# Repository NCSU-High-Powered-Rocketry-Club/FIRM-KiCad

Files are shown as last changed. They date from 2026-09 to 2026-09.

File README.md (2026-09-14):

# FIRM — Filtered Inertial Rotational Module

This repository contains the KiCad project files for the Filtered Inertial Rotational Module (FIRM). FIRM is a high-performance inertial sensing and rotation sensing module developed for flight instrumentation and payload monitoring. The repository includes schematic symbols, PCB footprints, 3D models, and all board files necessary to review, edit and manufacture the module.

---

## Quick Start — open the project

1. Install KiCad (see [Install & Setup](#install--setup-kicad) below).
2. Clone the repository:
```bash
git clone https://github.com/NCSU-High-Powered-Rocketry-Club/FIRM-KiCad.git
```

---

## Install & Setup

First, install KiCad from [kicad.org](https://kicad.org/download/). We recommend using the latest stable release of KiCad for new designs.

### After installation
- Open the `FIRM.kicad_pro` project. KiCad will use the `sym-lib-table` and `fp-lib-table` files included here if you open the board/schematic from this checkout.
- If KiCad shows missing library warnings, update the Project Library Tables or use the library manager to add the project's `sym-lib-table` and `fp-lib-table`.

---

## Repository structure

Root-level description (key files/folders):

- `FIRM.kicad_sch` — schematic
- `FIRM.kicad_pcb` — PCB layout
- `FIRM.kicad_pro` — KiCad project file that links schematics, board and library tables
- `sym-lib-table` — project symbol library table that makes project-local symbols available to Eeschema
- `fp-lib-table` — project footprint library table that makes project-local footprints available
- `3dmodels/` — 3D STEP/WRL models used with footprints
- `symbols/` — human-editable symbol libraries (e.g., `connectors.kicad_sym`, `sensors.kicad_sym`)
- `footprints/` — footprint libraries as `.pretty` directories
- `FIRM_Interestlaunch/` — FIRM variant which was milled in the Makerspace.

---

## Library handling

We keep the component libraries inside the HPRC-KiCad-Library so that components can be reused across different HPRC projects.

Make sure to follow the "Setup" instructions [here](
https://github.com/NCSU-High-Powered-Rocketry-Club/HPRC-KiCad-Library)

---

## Good Practices & Design Rules

- Keep schematic symbols generic and footprints specific: do not hardcode assembly-side changes into symbols.
- Look at the existing schematic to see how we do things and try to be consistent.
- Save new libraries to the project-local tables (not global) to keep designs reproducible.
- Keep PCB footprints accurate — use accurate courtyard, 3D models, and update packaging information.
- Validate with DRC (PCB Editor > Inspect > Design Rules Checker) and ERC (Eeschema > Tools > ERC) before committing changes.
- When collaborating, include notes about part sources (Mouser/Digikey vendor links), footprints used, and any custom pad or thickness changes.

---

## Release & Manufacturing Checklist

Before requesting fab or assembling a board, run this checklist:
1. Run ERC (Eeschema > Tools > ERC) and fix all warnings.
2. Run DRC in PCB Editor and resolve all errors.
3. Create a BOM and confirm manufacturer part numbers and footprints match.
4. Generate Gerbers and drill files (Plot + Generate Drill Files) and inspect them in GerbView.
5. Check 3D model alignment in PCB Editor (View > 3D Viewer) to ensure components fit.
6. Tag or branch the repo in Git to preserve the release snapshot.

---

## Git Collaboration and Merge Process

KiCad collaboration using git is difficult due to the KiCad file format. For example, moving a few symbols in a schematic will cause many lines to be edited, which greatly increases the chances of merge conflicts.
1. Create an issue for your feature if there isn't one already.
2. Create a branch including your name and the issue number ex: name-fix-XX or name-add-XX
    - It is best practice to suffix your branch name with a very short description/wordrelated to your change
3. Implement your change on your branch
4. Create a pull request (PR) for your change. Make sure to include images of the schematic or pcb design as well as reasons behind design decision. Request reviews from the issue creator or relevant contributors. You should need one approval to merge.
5. Merge your change into main. You will probably have to and should be able to force merge into main. 
    - However, if someone made change in between the time your branched from main and need to merge, you will have to do an unconvential merge process. 
    - You need a clean branch off the new main for this; this clean branch can either be a new branch you create, or your feature branch with all your changes reverted with main force merged into it. Then, access your changes and copy (ctrl-c copy) your symbols/components.
    - Now, open your clean branch to paste and position your changes. Commit this and update your PR or create a new one linking to your old one, and try to merge your changes as soon as possible.

## License

See `LICENSE` at the repo root for licensing details.

---

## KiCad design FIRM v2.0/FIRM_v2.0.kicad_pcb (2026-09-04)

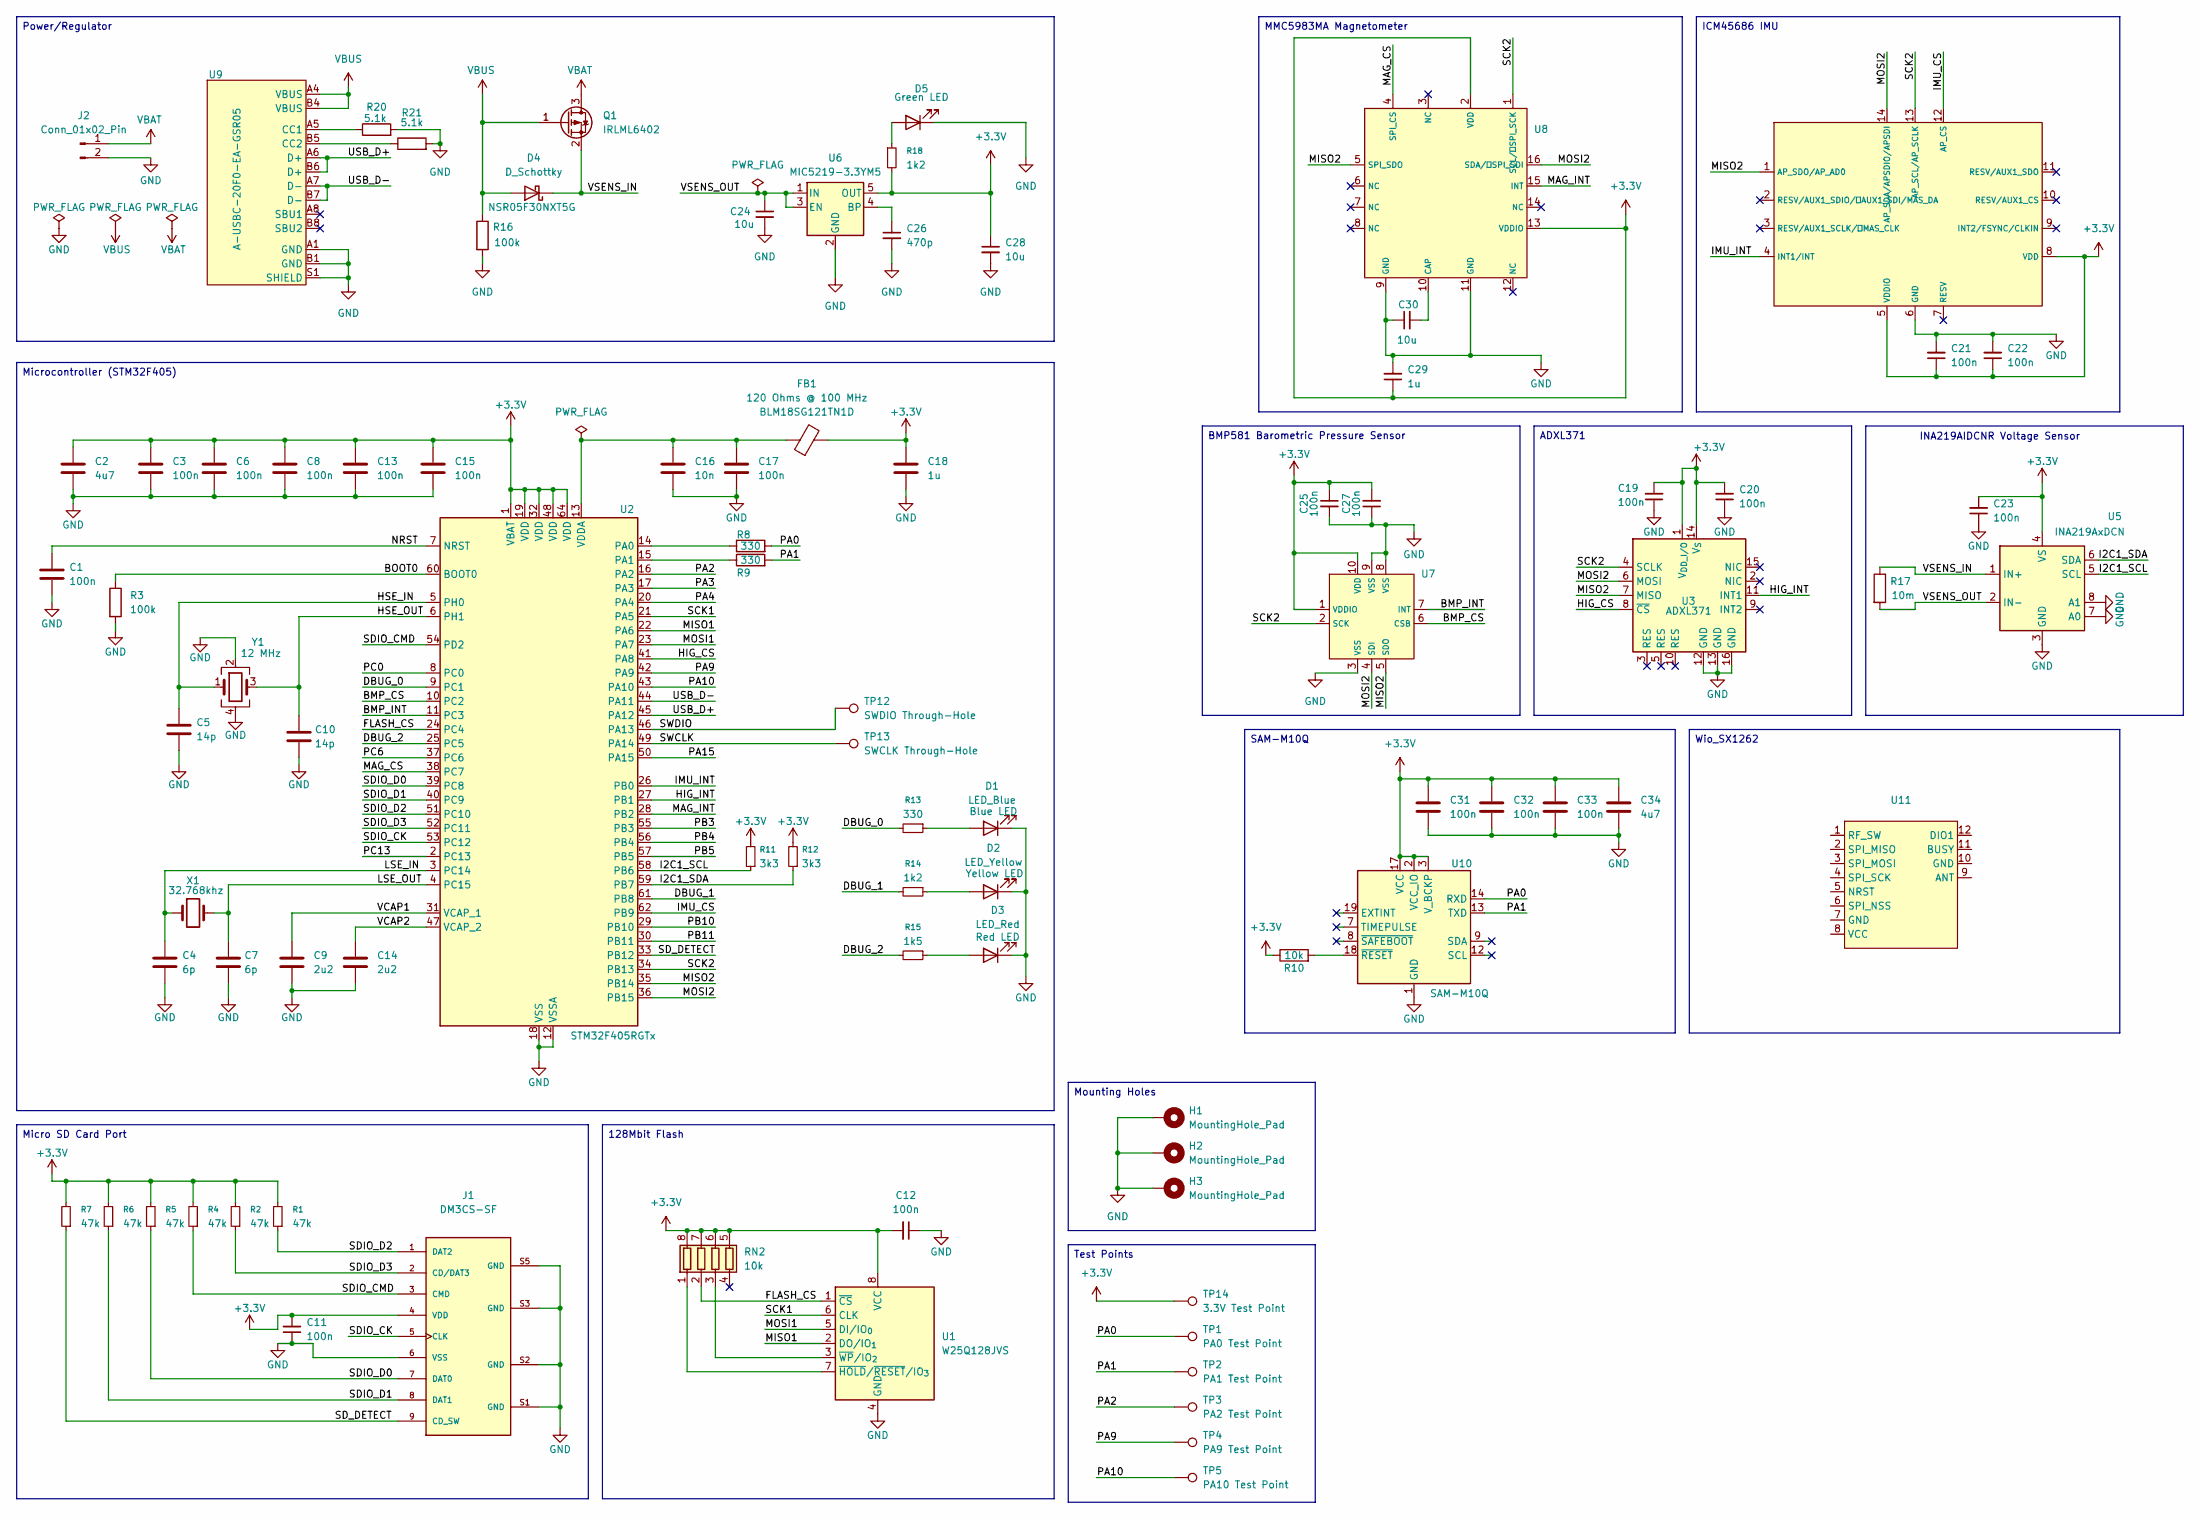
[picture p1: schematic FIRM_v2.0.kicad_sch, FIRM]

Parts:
C1, C3, C6, C8, C11, C12, C13, C15, C17, C19, C20, C21, C22, C23, C25, C27, C31, C32, C33: 100n; C_0402_1005Metric; MPN C1590; Digikey PN 1276-1043-1-ND
C2, C34: 4u7; C_0402_1005Metric; MPN C1705; Digikey PN 1276-1482-1-ND
C4, C7: 6p; C_0402_1005Metric; MPN C37474; Digikey PN 311-3714-1-ND
C5, C10: 14p; C_0402_1005Metric; MPN C5360816; Digikey PN 490-GJM1555C1H140FB01DCT-ND
C9, C14: 2u2; C_0402_1005Metric; MPN C1607; Digikey PN 490-10012-1-ND
C16: 10n; C_0402_1005Metric; MPN C1589; Digikey PN 490-1313-1-ND
C18, C29: 1u; C_0402_1005Metric; MPN C1592; Digikey PN 1276-1067-1-ND
C24, C28, C30: 10u; C_0402_1005Metric; MPN C1691; Digikey PN 1276-1451-1-ND
C26: 470p; C_0402_1005Metric; MPN C1620; Digikey PN 490-1300-1-ND
D1: LED_Blue; LED_0402_1005Metric; MPN C2293; Digikey PN 160-LTST-C281TBKTCT-ND
D2: LED_Yellow; LED_0402_1005Metric; MPN C2296; Digikey PN 160-LTST-C281KSKTCT-ND
D3: LED_Red; LED_0402_1005Metric; MPN C84256; Digikey PN 160-LTST-C281KRKTCT-ND
D4: D_Schottky; D_schottky_NSR05F30NXT5G; Digikey PN NSR05F30NXT5GOSCT-ND
D5: LED_Green; LED_0402_1005Metric; MPN C2297; Digikey PN 160-LTST-C281KGKTCT-ND
FB1: 120 Ohms @ 100 MHz; L_0603_1608Metric; Digikey PN 490-3996-1-ND
H1, H2, H3: MountingHole_Pad; MountingHole_2.2mm_M2_Pad_Via
J1: DM3CS-SF; HRS_DM3CS-SF; PARTREV n/a; Digikey PN HR1972CT-ND
J2: Conn_01x02_Pin; power_headers
Q1: IRLML6402; SOT-23; MPN C22367042; Digikey PN IRLML6402PBFCT-ND
R1, R2, R4, R5, R6, R7: 47k; R_0402_1005Metric; MPN C22356633; Digikey PN 311-47.0KLRCT-ND
R3, R16: 100k; R_0402_1005Metric; MPN C177329; Digikey PN P100KLCT-ND
R8, R9: 330
R10: 10k
R11, R12: 3k3; R_0402_1005Metric; MPN C22356633; Digikey PN P3.3KDCCT-ND
R13: 330; R_0402_1005Metric; MPN C177341; Digikey PN 311-330LRCT-ND
R14, R18: 1k2; R_0402_1005Metric; MPN C22369820; Digikey PN 311-1.2KJRCT-ND
R15: 1k5; R_0402_1005Metric; MPN C22369819; Digikey PN 311-1.50KLRCT-ND
R17: 10m; R_0402_1005Metric; Digikey PN P19181CT-ND
R20, R21: 5.1k; R_0402_1005Metric; MPN C177348; Digikey PN P5.1KDCCT-ND
RN2: 10k; R_Array_YC104; Digikey PN 13-YC104-FR-0710KLCT-ND
TP1: PA0 Test Point; Testpoint_1.5x1.5mm_1.0mm
TP2: PA1 Test Point; Testpoint_1.5x1.5mm_1.0mm
TP3: PA2 Test Point; Testpoint_1.5x1.5mm_1.0mm
TP4: PA9 Test Point; Testpoint_1.5x1.5mm_1.0mm
TP5: PA10 Test Point; Testpoint_1.5x1.5mm_1.0mm
TP12: SWDIO Through-Hole; Testpoint_1.5x1.5mm_1.0mm
TP13: SWCLK Through-Hole; Testpoint_1.5x1.5mm_1.0mm
TP14: 3.3V Test Point; Testpoint_1.5x1.5mm_1.0mm
U1: W25Q128JVS; SOIC-8_5.3x5.3mm_P1.27mm; Digikey PN 256-W25Q128JVSIQTRCT-ND
U2: STM32F405RGTx; LQFP-64_10x10mm_P0.5mm; MPN C15742; Digikey PN 497-11767-ND
U3: ADXL371; Analog_LGA-16_3.25x3mm_P0.5mm_LayoutBorder3x5y; Digikey PN 505-ADXL371BCCZ-RL7CT-ND
U4: IC_ICM-45686; MPN C22459454; Digikey PN 1428-ICM-45686CT-ND
U5: INA219AxDCN; SOT-23-8; Digikey PN 296-23770-1-ND
U6: MIC5219-3.3YM5; SOT-23-5; MPN C5370977; Digikey PN 576-1281-1-ND
U7: BMPFootprintNoSolderMask; MPN C5362283; Digikey PN 828-BMP581CT-ND
U8: IC_MMC5983MA; MPN C404329; Digikey PN 1267-MMC5983MACT-ND
U9: A-USBC-20F0-EA-GSR05; MPN C22036153; Digikey PN 123-A-USBC-20F0-EA-GSR05CT-ND
U10: SAM-M10Q; ublox_SAM-M8Q
U11: Wio_SX1262
X1: 32.768khz; Crystal_ECS-.327-6-12RR-TR; Digikey PN XC3096CT-ND
Y1: 12 MHz; Crystal_ECS-120-10-36B2-CWY-TR; Digikey PN 50-ECS-120-10-36B2-CWY-TRCT-ND

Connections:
+3.3V: C2.1, C3.1, C6.1, C8.1, C11.2, C12.2, C13.1, C15.1, C18.1, C19.2, C20.2, C21.1, C22.1, C23.2, C25.1, C27.2, C28.1, C29.1, C31.1, C32.1, C33.1, C34.1, FB1.2, J1.4 (VDD), R1.2, R2.2, R4.2, R5.2, R6.2, R7.2, R10.1, R11.2, R12.2, R18.2, RN2.5 (R4.2), RN2.6 (R3.2), RN2.7 (R2.2), RN2.8 (R1.2), TP14.1, U1.8 (VCC), U2.1 (VBAT), U2.19 (VDD), U2.32 (VDD), U2.48 (VDD), U2.64 (VDD), U3.1 (V_{DD_I/O}), U3.14 (V_{S}), U4.5 (VDDIO), U4.8 (VDD), U5.4 (VS), U6.5 (OUT), U7.1 (VDDIO), U7.10 (VDD), U8.2 (VDD), U8.13 (VDDIO), U10.2 (VCC_IO), U10.3 (V_BCKP), U10.17 (VCC)
/BMP_CS: U2.10 (PC2), U7.6 (CSB)
/BMP_INT: U2.11 (PC3), U7.7 (INT)
/BOOT0: R3.1, U2.60 (BOOT0)
/DBUG_0: R13.2, U2.9 (PC1)
/DBUG_1: R14.2, U2.61 (PB8)
/DBUG_2: R15.2, U2.25 (PC5)
/FLASH_CS: RN2.2 (R2.1), U1.1 (~CS), U2.24 (PC4)
/HIG_CS: U2.41 (PA8), U3.8 (~CS)
/HIG_INT: U2.27 (PB1), U3.11 (INT1)
/HSE_IN: C5.1, U2.5 (PH0), Y1.1
/HSE_OUT: C10.1, U2.6 (PH1), Y1.3
/I2C1_SCL: R11.1, U2.58 (PB6), U5.5 (SCL)
/I2C1_SDA: R12.1, U2.59 (PB7), U5.6 (SDA)
/IMU_CS: U2.62 (PB9), U4.12 (AP_CS)
/IMU_INT: U2.26 (PB0), U4.4 (INT1/INT)
/LSE_IN: C4.1, U2.3 (PC14), X1.1
/LSE_OUT: C7.1, U2.4 (PC15), X1.2
/MAG_CS: U2.38 (PC7), U8.4 (SPI_CS)
/MAG_INT: U2.28 (PB2), U8.15 (INT)
/MISO1: U1.2 (DO/IO_{1}), U2.22 (PA6)
/MISO2: U2.35 (PB14), U3.7 (MISO), U4.1 (AP_SDO/AP_AD0), U7.5 (SDO), U8.5 (SPI_SDO)
/MOSI1: U1.5 (DI/IO_{0}), U2.23 (PA7)
/MOSI2: U2.36 (PB15), U3.6 (MOSI), U4.14 (AP_SDA/APSDIO/APSDI), U7.4 (SDI), U8.16 (SDA/ SPI_SDI)
/NRST: C1.1, U2.7 (NRST)
/PA0: R8.2, TP1.1, U10.14 (RXD)
/PA1: R9.2, TP2.1, U10.13 (TXD)
/PA2: TP3.1, U2.16 (PA2)
/PA3: U2.17 (PA3)
/PA4: U2.20 (PA4)
/PA9: TP4.1, U2.42 (PA9)
/PA10: TP5.1, U2.43 (PA10)
/PA15: U2.50 (PA15)
/PB3: U2.55 (PB3)
/PB4: U2.56 (PB4)
/PB5: U2.57 (PB5)
/PB10: U2.29 (PB10)
/PB11: U2.30 (PB11)
/PC0: U2.8 (PC0)
/PC6: U2.37 (PC6)
/PC13: U2.2 (PC13)
/SCK1: U1.6 (CLK), U2.21 (PA5)
/SCK2: U2.34 (PB13), U3.4 (SCLK), U4.13 (AP_SCL/AP_SCLK), U7.2 (SCK), U8.1 (SCL/ SPI_SCK)
/SDIO_CK: J1.5 (CLK), U2.53 (PC12)
/SDIO_CMD: J1.3 (CMD), R4.1, U2.54 (PD2)
/SDIO_D0: J1.7 (DAT0), R5.1, U2.39 (PC8)
/SDIO_D1: J1.8 (DAT1), R6.1, U2.40 (PC9)
/SDIO_D2: J1.1 (DAT2), R1.1, U2.51 (PC10)
/SDIO_D3: J1.2 (CD/DAT3), R2.1, U2.52 (PC11)
/SD_DETECT: J1.9 (CD_SW), R7.1, U2.33 (PB12)
/SWCLK: TP13.1, U2.49 (PA14)
/SWDIO: TP12.1, U2.46 (PA13)
/USB_D+: U2.45 (PA12), U9.A6 (D+), U9.B6 (D+)
/USB_D-: U2.44 (PA11), U9.A7 (D-), U9.B7 (D-)
/VCAP1: C9.1, U2.31 (VCAP_1)
/VCAP2: C14.1, U2.47 (VCAP_2)
/VSENS_IN: D4.1 (K), Q1.2 (S), R17.1, U5.1 (IN+)
/VSENS_OUT: C24.1, R17.2, U5.2 (IN-), U6.1 (IN), U6.3 (EN)
unnamed: D1.2 (A), R13.1
unnamed: D2.2 (A), R14.1
unnamed: D3.2 (A), R15.1
unnamed: D5.2 (A), R18.1
unnamed: RN2.1 (R1.1), U1.7 (~HOLD/~RESET/IO_{3})
unnamed: RN2.3 (R3.1), U1.3 (~WP/IO_{2})
unnamed: R8.1, U2.14 (PA0)
unnamed: R9.1, U2.15 (PA1)
unnamed: C16.1, C17.1, FB1.1, U2.13 (VDDA)
unnamed: C26.1, U6.4 (BP)
unnamed: C30.2, U8.10 (CAP)
unnamed: R20.1, U9.A5 (CC1)
unnamed: R21.1, U9.B5 (CC2)
unnamed: R10.2, U10.18 (~RESET)
VBAT: J2.1, Q1.3 (D)
VBUS: D4.2 (A), Q1.1 (G), R16.1, U9.A4 (VBUS), U9.B4 (VBUS)

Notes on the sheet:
INA219AIDCNR Voltage Sensor
Wio_SX1262
SAM-M10Q
128Mbit Flash
Test Points
Microcontroller (STM32F405)
Power/Regulator
MMC5983MA Magnetometer
BMP581 Barometric Pressure Sensor
Mounting Holes
Micro SD Card Port
ADXL371
ICM45686 IMU

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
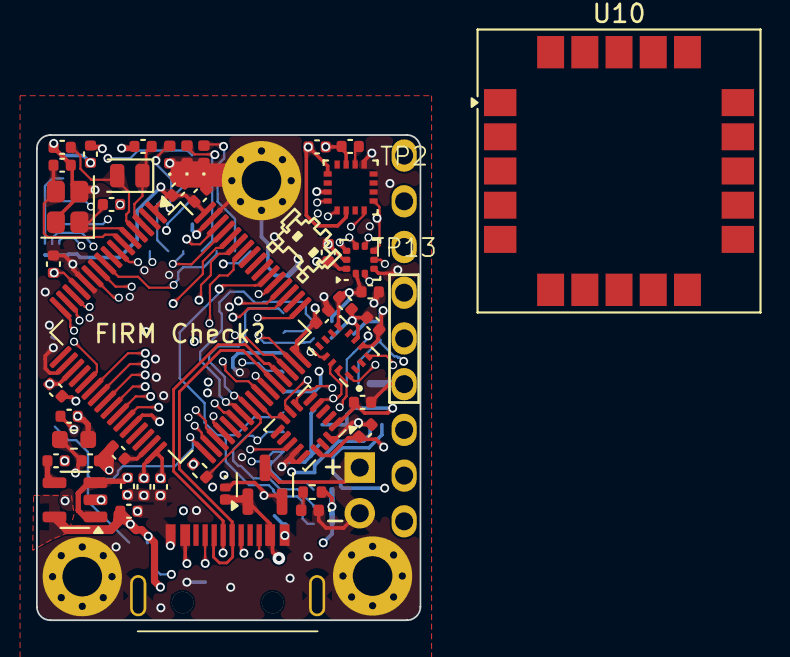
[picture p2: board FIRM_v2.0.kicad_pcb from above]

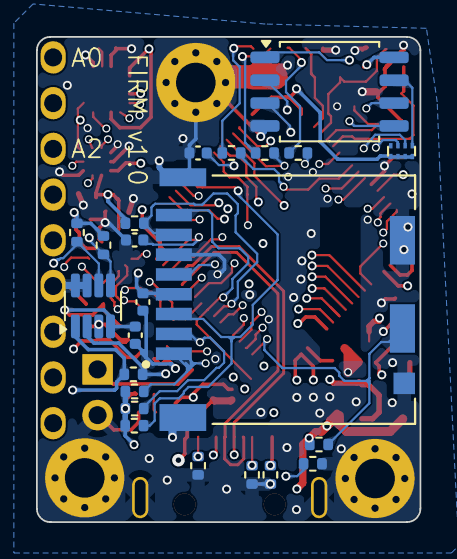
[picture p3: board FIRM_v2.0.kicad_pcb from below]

Board: 8 copper layers, 21.3 x 27.0 mm, 81 parts (23 on the bottom side), 61 nets.

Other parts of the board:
GD: GND Test Point; Testpoint_1.5x1.5mm_1.0mm

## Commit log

2025-12-22 winter schematic changes
    added high-g accelerometer, changed magnetometer to spi only, changed debug pins, added spi/i2c test pads, added INT/CS test pads, and replaced NRST button with test pad.
    [FIRM.kicad_sch]
2025-12-23 Added voltage sensor
    [FIRM.kicad_sch]
2025-12-29 Made components 0402s
    [FIRM.kicad_sch]
2025-12-29 Assign footprint using local libraries
    [FIRM.kicad_sch]
2025-12-30 Make changes to test points, pads, usb-c, jlcpcb settings
    [FIRM.kicad_sch]
2025-12-30 sub 600
    [FIRM.kicad_pcb]
2025-12-31 finished routing
    [FIRM.kicad_pcb, FIRM.kicad_sch]
2025-12-31 byebye drc errors
    [FIRM.kicad_pcb]
2026-01-02 add back decoupling capacitors for stm
    [FIRM.kicad_pcb, FIRM.kicad_sch]
2026-01-02 clean up and moved shunt resistor
    [FIRM.kicad_pcb]
2026-01-03 stuff for willy boy
    [FIRM.kicad_pcb]
2026-01-03 resistor arrays and smaller parts
    [FIRM.kicad_pcb, FIRM.kicad_sch]
2026-01-03 new flash chip
    [FIRM.kicad_pcb, FIRM.kicad_sch]
2026-01-04 cleanup and improved decoupling capacitor locations
    [FIRM.kicad_pcb, FIRM.kicad_sch]
2026-01-05 added back resistors
    [FIRM.kicad_pcb, FIRM.kicad_sch]
2026-01-06 finished routing resistors
    [FIRM.kicad_pcb]
2026-01-06 a lil bit of this a lil bit of that
    [FIRM.kicad_pcb]
2026-01-09 part numbers
    [FIRM.kicad_sch]
2026-01-10 fixed resistor
    [FIRM.kicad_pcb]
2026-01-13 get stuff ready
    [FIRM.kicad_pcb, FIRM.kicad_sch]
2026-01-16 Initial Six Layer
    Stackup is right board recommended in this video: https://youtu.be/ySuUZEjARPY?t=6617
    .
    [FIRM.kicad_pcb, FIRM.kicad_sch]
2026-01-16 Connected Second USB_D+ with Via
    Maybe this is okay?
    https://electronics.stackexchange.com/questions/209236/usb-signal-routing-swap-data-lines-using-vias?rq=1
    [FIRM.kicad_pcb]
2026-01-16 Fixed Ground Via Outside Board
    [FIRM.kicad_pcb]
2026-01-20 Minor Tweaks
    [FIRM.kicad_pcb]
2026-01-21 Improved DRC
    Based on JLCPCB settings
    [FIRM.kicad_pcb]
2026-01-21 Fixed Most Errors
    Mostly just spacing things out. One error remaining.
    [FIRM.kicad_pcb]
2026-01-21 Modified Schottky Barrier Diode, Connected +3.3v
    0 errors now, +3.3v is connected correctly.
    [FIRM.kicad_pcb]
2026-01-22 Teardrops, Better Power Connections
    💧
    [FIRM.kicad_pcb]
2026-01-22 8 Layer Conversion
    [FIRM.kicad_pcb]
2026-01-23 Increased Via Size
    Via hole is now 0.3mm and Via diameter is 0.5mm. Everything fits, no board resizing needed.
    [FIRM.kicad_pcb]
2026-01-23 Small Improvements
    Slightly better via techniques, better heat-sink-ish copper pour for the voltage regulator
    [FIRM.kicad_pcb]
2026-01-25 Stackup and Differential Pair Corrected
    DP trace width set to 0.16 for 90Ohm impedance calculated from JLCPCB and 82 Ohm impedance calculated by Saturn.
    Stackup inner copper thickness changed to 0.5oz.
    [FIRM.kicad_pcb]
2026-01-25 Fixed 2 DRC Errors
    [FIRM.kicad_pcb]
2026-01-27 Improved Stackup, Increased Trace Widths
    Stackup improved so signal layer aren't adjacent.
    Smallest trace width changed to 5 mils.
    Minimum via diameter is 0.45mm, there are still some 0.5mm where space allows.
    Added Gnd vias where space allowed
    Other minor improvements.
    [FIRM.kicad_pcb]
2026-01-27 Traces Straightening
    [FIRM.kicad_pcb]
2026-01-29 Trace improvements
    [FIRM.kicad_pcb]
2026-01-29 Minor Changes
    Trying to avoid acid traps
    [FIRM.kicad_pcb]
2026-03-06 Accept All Incoming Changes
    [FIRM.kicad_sch]
2026-03-06 Cleanup merge errors
    The merge thingy created random duplicates of sensors and components scattered around the schematic, so i deleted the extra doohickeys
    [FIRM.kicad_sch]
2026-03-24 new stm and flash
    [DM3CS-SF.step, FIRM.kicad_pcb, FIRM.kicad_sch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]
2026-03-25 Update FIRM.kicad_sch
    Added connector pins with labels
    [FIRM.kicad_sch]
2026-03-25 Update FIRM.kicad_sch
    Changed pin labels
    [FIRM.kicad_sch]
2026-03-26 Update FIRM.kicad_sch
    Started updating STM32H743VITx schematic
    [FIRM.kicad_sch]
2026-03-31 Updated to the new STM
    [FIRM.kicad_sch]
2026-04-02 Added Pinouts to STM
    [FIRM.kicad_sch]
2026-04-02 fixed pinout
    [FIRM.kicad_sch]
2026-04-06 Dedicated Folder Organization 2.0
    [FIRM.kicad_pcb, FIRM.kicad_sch]
2026-04-06 Revert "Dedicated Folder Organization 2.0"
    This reverts commit 51f450398a150c39cebc4335cbc06f6e2cefbeb5.
    [FIRM.kicad_pcb, FIRM.kicad_sch]
2026-04-16 Updated STM names
    [FIRM.kicad_sch]
2026-04-21 Started adding Pins From Shoe
    Started added pins from shoe, unsure about global variable and connection based on previous schematic.
    [FIRM.kicad_sch]
2026-04-22 Update test pins
    [FIRM.kicad_sch]
2026-04-28 Updated testpoints
    [FIRM.kicad_sch]
2026-08-17 Add 3D models for USB-C, microSD and IMU/magnetometer footprints
    Wire up the STEP files already sitting in 3dmodels/ and add a stock
    KiCad model for the USB-C receptacle. Models are added to both the
    footprint libraries and the placed instances in the board.
    - U4 IC_ICM-45686 and U8 IC_MMC5983MA: local STEP files are authored
    Y-up, so both take (rotate (xyz -90 0 0)).
    - J1 HRS_DM3CS-SF: local STEP is Z-up but modeled ~224mm off origin,
    corrected with (offset (xyz -224.29 -126.3636 0)).
    - U9 A-USBC-20F0-EA-GSR05: no vendor model available; uses the KiCad
    GCT USB4105 receptacle as a visual stand-in. Body envelope and
    signal pad row match, but it is a 16P part with shield legs at
    +/-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
    [FIRM.kicad_pcb]
2026-08-17 Fix 3D model paths that pointed at non-existent files, use vendor BMP581 model
    U3, X1 and D4 already had (model ...) entries, but the referenced files
    are not present in the KiCad 3D library, so nothing rendered.
    - U3 ADXL371: Sensor_Motion.3dshapes is not installed; the identical
    LGA-16_3x3mm_P0.5mm_LayoutBorder3x5y.step lives in Package_LGA.3dshapes.
    - X1 32.768kHz: Crystal_SMD_2012-2Pin_2.0x1.2mm does not exist under that
    name; MicroCrystal CC8V-T1A is the same 2.0x1.2mm 2-pin package.
    - D4 NSR05F30NXT5G: no 0402 diode model ships with this install (Diode_SMD
    starts at 0603), so it borrows the identical 0402 chip body from
    Resistor_SMD as a stand-in.
    Also switch the BMP581 footp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
    [FIRM.kicad_pcb]
2026-08-18 Add a real 3D model for the U9 USB-C receptacle
    No free CAD model exists for the Assmann WSW A-USBC-20F0-EA-GSR05: the
    manufacturer's product page carries only the drawing, Digi-Key has no CAD
    links, the LCSC/EasyEDA API doesn't know C22036153, and SnapMagic lists
    only the sibling GSR06 behind a paid STEP service.
    So build one from the manufacturer drawing (ASS 9424CO rev00) with
    FreeCAD instead, and drop the KiCad GCT USB4105 stand-in that was
    standing in for it. Dimensions taken from the drawing: 10.84 flange /
    10.34 shell / 8.94 mating nose, 8.34 x 2.56 port on a 2.25 centreline,
    5.06 overall height on a 0.37 standoff, 2x o1.00 locating posts at 5.00
    spacing, shield tabs at 9.94, and the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
    [A-USBC-20F0-EA-GSR05.step, FIRM.kicad_pcb]
2026-08-20 Use the real USB-C model from PR #7 for U9
    PR #7 (harshil21) carries a genuine solid for this connector, converted
    from the vendor SLDPRT via Onshape, so drop the model I reconstructed
    from the drawing in 6175c9f and take theirs instead.
    Only the model comes across - the rest of PR #7 (the KiCAD v10 migration
    and the soldermask/silkscreen colour changes) is left alone, so this
    stays a two-line change plus the new file.
    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
    [A-USBC-20F0-EA-GSR05.step, FIRM.kicad_pcb, firm_usbc.step]
2026-09-01 Fix USB-C Model, Fix Silkscreen Color
    It was the incorrect length previously. Also reapplied Harshil's mask and silkscreen colors.
    [FIRM.kicad_pcb]
2026-09-02 Dedicated Folder Organization v1.1
    [FIRM.kicad_pcb, FIRM.kicad_sch]
2026-09-02 Save in KiCad 10.0
    [FIRM.kicad_pcb, FIRM.kicad_sch]
2026-09-02 Rename v1.1 Project
    [FIRM_v1.1.kicad_pcb, FIRM_v1.1.kicad_sch]
2026-09-02 Save KiCad Files
    Saved files so they get automatically converted to the new "FIRM_v1.1" project name
    [FIRM_v1.1.kicad_pcb, FIRM_v1.1.kicad_sch]
2026-09-02 Rename v2.0 Project
    [FIRM_v2.0.kicad_pcb, FIRM_v2.0.kicad_sch]
2026-09-02 Reorg and Rename v1.0
    [FIRM_v1.0.kicad_pcb, FIRM_v1.0.kicad_sch]
2026-09-03 Remove Unnecessary Library Files
    footprints, symbols, 3dmodels folders are no longer needed because we are using a global library to store them.
    [BMP581.step, FIRM_v1.0.kicad_pcb, ICM-45686.step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]
2026-09-20 Added new flash chip
    Set up quadSPI with the new 1gbit flash chip.
    [FIRM_v1.1.kicad_pcb, FIRM_v1.1.kicad_sch, W25N01GVZEIG.STEP]
2026-09-20 Finished Pinout for STM
    Fixed Pin out and test Pins
    [FIRM_v1.1.kicad_sch]
2026-09-21 Schematic complete
    Everything on the pin out is complete and I have a STM32 Project complete with the correct pin out. I still have concerns regarding the Ferrite bead
    [FIRM_v1.1.kicad_sch]
2026-09-21 Slimed out the Ferrite Bead
    Took out the ferrite bead and connected to VDD
    [FIRM_v1.1.kicad_sch]
2026-09-28 Moved custom component to library
    [W25N01GVZEIG.STEP]
2026-09-28 Updated Pinout for STM and migrated schematics from shoe to 2.0
    [FIRM_v1.1.kicad_sch, FIRM_v2.0.kicad_sch]
2026-09-28 Add History to gitignore
    The .history files are automatically created by KiCad for local history and shouldn't be tracked.
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2026-10-11 Update FIRM 2.0 with new changes to flash, ADXL, and Voltage reg
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2026-10-18 Fixed Errors and switched out Regulator
    I tackled errors described in the pull request. I also switched out the regulator . I need to still fix all ERC warnings and pick out a part for our inductor in the regulator.
2026-10-19 Got rid of ERC errors, switched out capacitors packaging for regulator, and chose out a murata inductor for regulator
    Inductor chosen:
    https://www.murata.com/~/media/webrenewal/products/inductor/chip/tokoproducts/wirewoundmetalalloychiptype/m_dfe252012f.ashx
2026-10-19 Fixed ADXL375 , and SPI3 line pin out
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2026-10-22 Fixed Resistor dividers
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
